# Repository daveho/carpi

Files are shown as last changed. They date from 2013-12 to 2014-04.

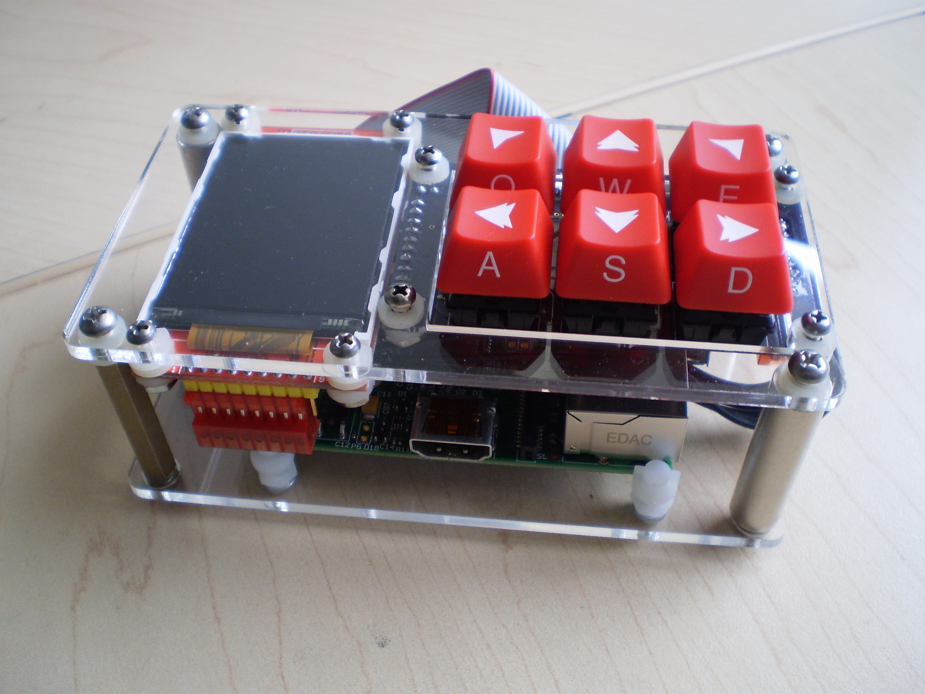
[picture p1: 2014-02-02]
enclosure/pic-big.jpg

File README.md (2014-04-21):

Hardware design and code for Raspberry Pi based car entertainment device.  Everything is up and running and works fairly well at this point.  I wrote a [blog post](http://daveho.github.io/2014/04/19/carpi-car-videos-with-the-raspberry-pi.html) that summarizes the project.

The [wiki](https://github.com/daveho/carpi/wiki) has complete information on building the device and installing the software.

Everything (software and hardware) is open source: see the file
LICENSES.txt for details.

The basic idea is being able to play videos and music
from the Raspberry Pi.  The user interface consists
of a 2.2" LCD and 6 keyswitches.  A sandwich-style
enclosure consisting of two pieces of laser-cut acrylic
and various bits of hardware has been designed and assembled.
The "enclosure" directory has complete CAD drawings.

Here is a photo of the assembled device (with the Raspberry Pi,
the LCD module, and the keyswitches):



Current status of the software is

* It's a console (ncurses) app.  This probably won't change,
  although the software makes a clean separation between
  controllers and views, and the former are completely
  independent of the latter, so a proper GUI interface
  could be supported.
* The LCD display is assumed to be 240x320, accessed as
  a Linux framebuffer device with fbcons.  (Specifically,
  an SPI-based LCD using the ILI9340 controller chip,
  supported by fbtft using the "adafruit22a" driver.
  Note that the LCD I'm using isn't specifically the
  Adafruit one, but appears to be completely compatible.)
  With a 8x16 font this gives us a 30x20 text display.
* Music playing works using mpg321 and ogg123 via the
  remote control interface (actually ogg123 playback doesn't
  work, need to investigate this).
* Pushbutton input is supported using the RPi's GPIO.
* Video playing is supported by running omxplayer as a
  subprocess, with video output going to the composite output
  (because composite video monitors for cars are super cheap).

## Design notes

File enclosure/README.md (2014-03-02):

The enclosure designs were created with LibreCAD.

Here's how it looks completely assembled (click for large version)!



Files:

* plate2.dxf - the main drawing showing all of the features of the top and bottom plates of the enclosure, including the Raspberry Pi, the LCD, the buttons PCB, standoffs, etc.
* top2.dxf, bottom2.dxf - drawings with just the cuts needed for the top and bottom plates
* combined2.dxf - combined drawing of top and bottom plates; this can be submitted to your favorite laser cutting service (I personally think [Pololu](http://www.pololu.com/) is awesome!)
* ibex\_rpi\_model\_b\_v1\_00.dxf - CAD drawing of the Raspberry Pi,
  taken from http://www.raspberry-projects.com/pi/pi-hardware/model-b-cad
* ibex\_rpi\_model\_b\_v1\_00\_correct\_orientation.dxf -
  same as above, but shown as a top view instead of a bottom view
* lcd.dxf - drawing of just the LCD module, showing screw hole locations
* buttons2.dxf - drawing of outline and screw holes for buttons PCB (v0.2, with Cherry MX keyswitches)

The **old** subdirectory has a previous version of the enclosure where the buttons were 12mm x 12mm pushbuttons: not recommended, since I messed up the header orientation on the v0.1 buttons PCB, and it will be very difficult to connect it to the Raspberry Pi.

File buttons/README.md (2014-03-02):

This directory has schematics, PCB layout, and firmware for the
board that has the pushbuttons on it.  An attiny2313 or attiny4313
microcontroller does the debouncing.  This board also has a header
that connects to the LCD.

**buttons2.sch** and **buttons2.brd** are the schematic and board layout,
in Eagle CAD.

Rendering (via [OSH Park](http://www.oshpark.com), which is where I had the boards fabricated):

<a href="https://raw.github.com/daveho/carpi/master/buttons/pcbBottom.png">bottom of PCB</a>

<a href="https://raw.github.com/daveho/carpi/master/buttons/pcbTop.png">top of PCB</a>

Note that the PCB uses Cherry MX keyboard switches.  **cherrymx.lbr** is a
(very slightly) modified version of the following Eagle library:
https://github.com/c0z3n/cherrymx-eagle

[I sent a pull request with my changes, which were purely improvements
to the schematic symbol.]

**buttons.c** is the firmware that runs on the attiny2313.
**Makefile** will compile it (using avr-gcc) and program it to the
device (using avrdude).

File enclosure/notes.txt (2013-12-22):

ibex_rpi_model_b_v1_00.dxf is from:
  http://www.raspberry-projects.com/pi/pi-hardware/model-b-cad

ibex_rpi_model_b_v1_00_correct_orientation.dxf
  This is a modified version of the above file with the contents
  mirrored to show a top view rather than a bottom view.
  (Not quite sure why the original was a bottom view.)

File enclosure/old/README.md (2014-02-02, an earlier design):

This is an old version of the enclosure design.  You don't want to use this.

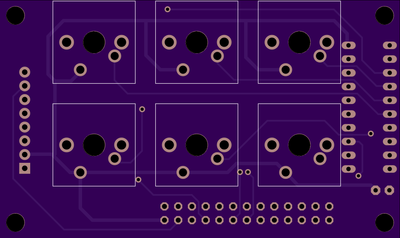
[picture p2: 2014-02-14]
buttons/pcbTop-sm.png

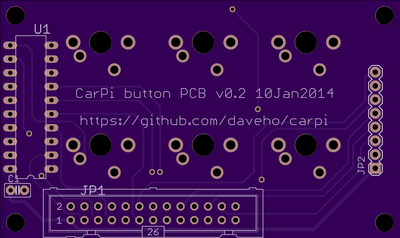
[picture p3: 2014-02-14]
buttons/pcbBottom-sm.png

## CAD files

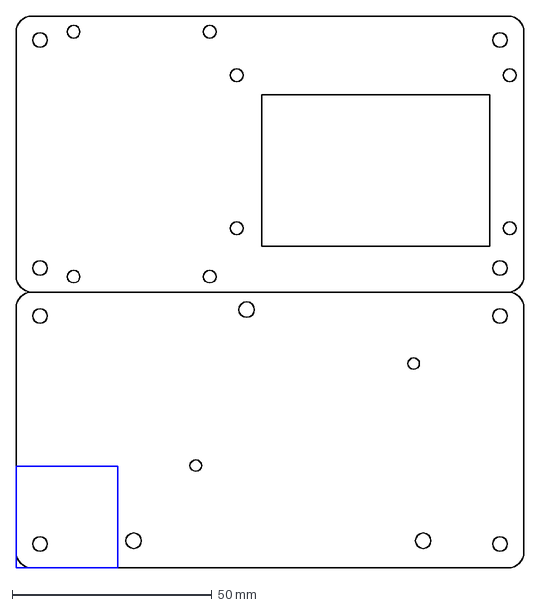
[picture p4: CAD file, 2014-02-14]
enclosure/combined2.dxf
127.0 x 138.0 mm

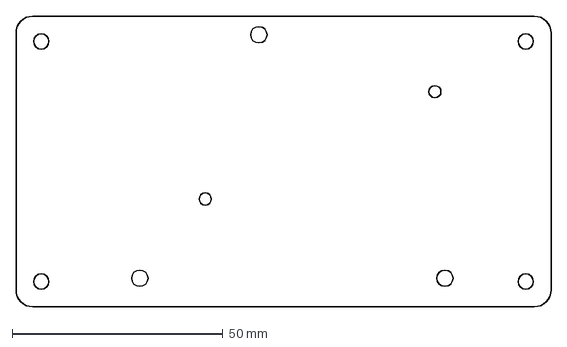
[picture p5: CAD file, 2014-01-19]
enclosure/bottom2.dxf
127.0 x 69.0 mm

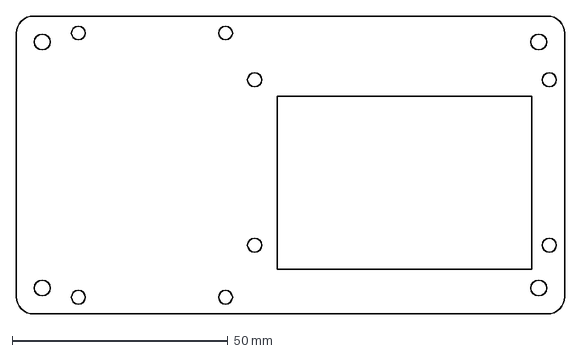
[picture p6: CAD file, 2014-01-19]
enclosure/top2.dxf
127.0 x 69.0 mm

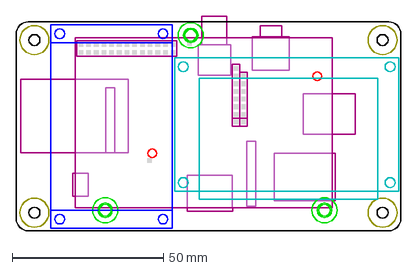
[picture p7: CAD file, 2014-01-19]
enclosure/plate2.dxf
127.0 x 70.9 mm

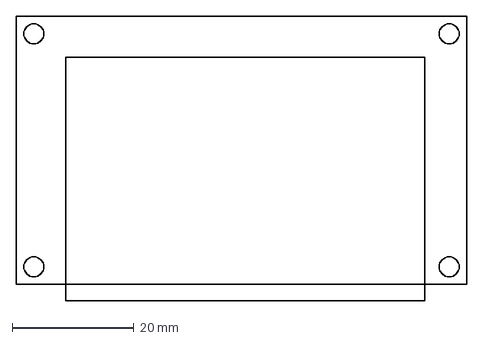
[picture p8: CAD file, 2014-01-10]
enclosure/buttons2.dxf
74.0 x 46.7 mm

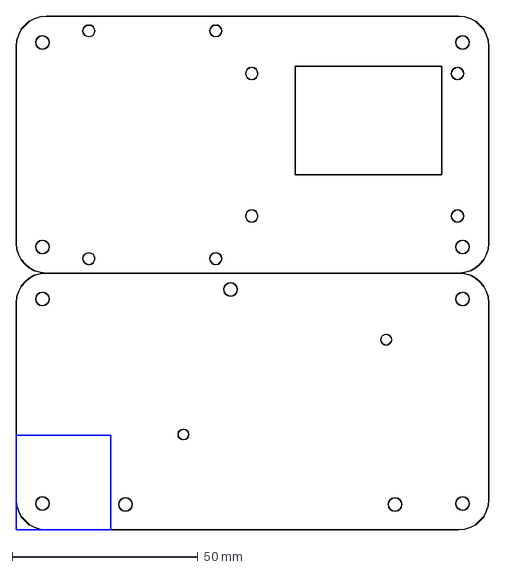
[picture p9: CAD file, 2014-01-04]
enclosure/combined.dxf
127.0 x 138.0 mm

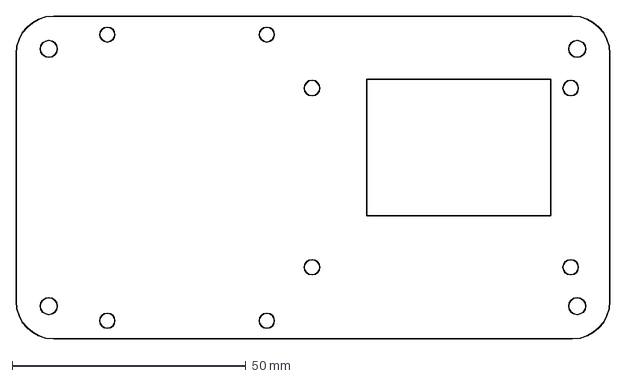
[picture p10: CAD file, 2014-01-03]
enclosure/top.dxf
127.0 x 69.0 mm

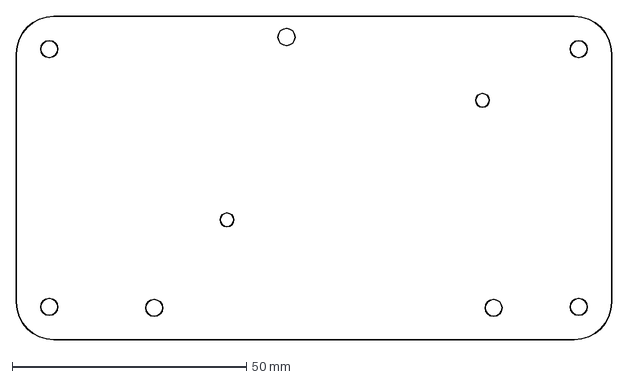
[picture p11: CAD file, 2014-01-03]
enclosure/bottom.dxf
127.0 x 69.0 mm

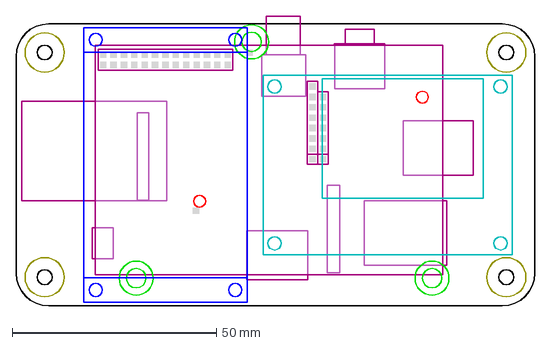
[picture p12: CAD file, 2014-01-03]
enclosure/plate.dxf
127.0 x 70.9 mm

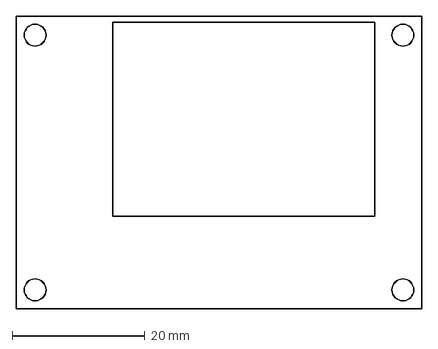
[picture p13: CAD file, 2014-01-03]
enclosure/buttons.dxf
61.0 x 44.0 mm

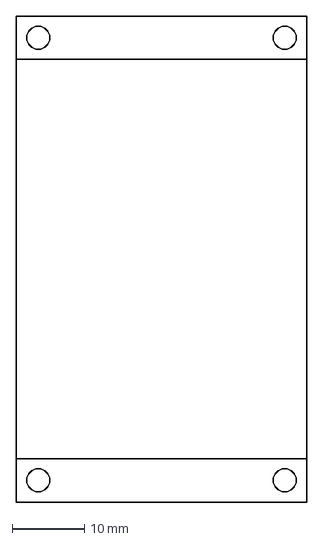
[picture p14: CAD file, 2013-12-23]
enclosure/lcd.dxf
40.1 x 67.2 mm

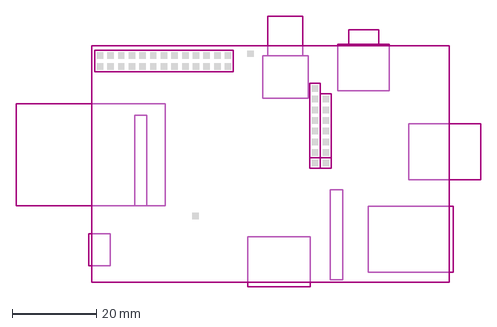
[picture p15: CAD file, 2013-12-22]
enclosure/ibex_rpi_model_b_v1_00_correct_orientation.dxf
110.5 x 64.5 mm

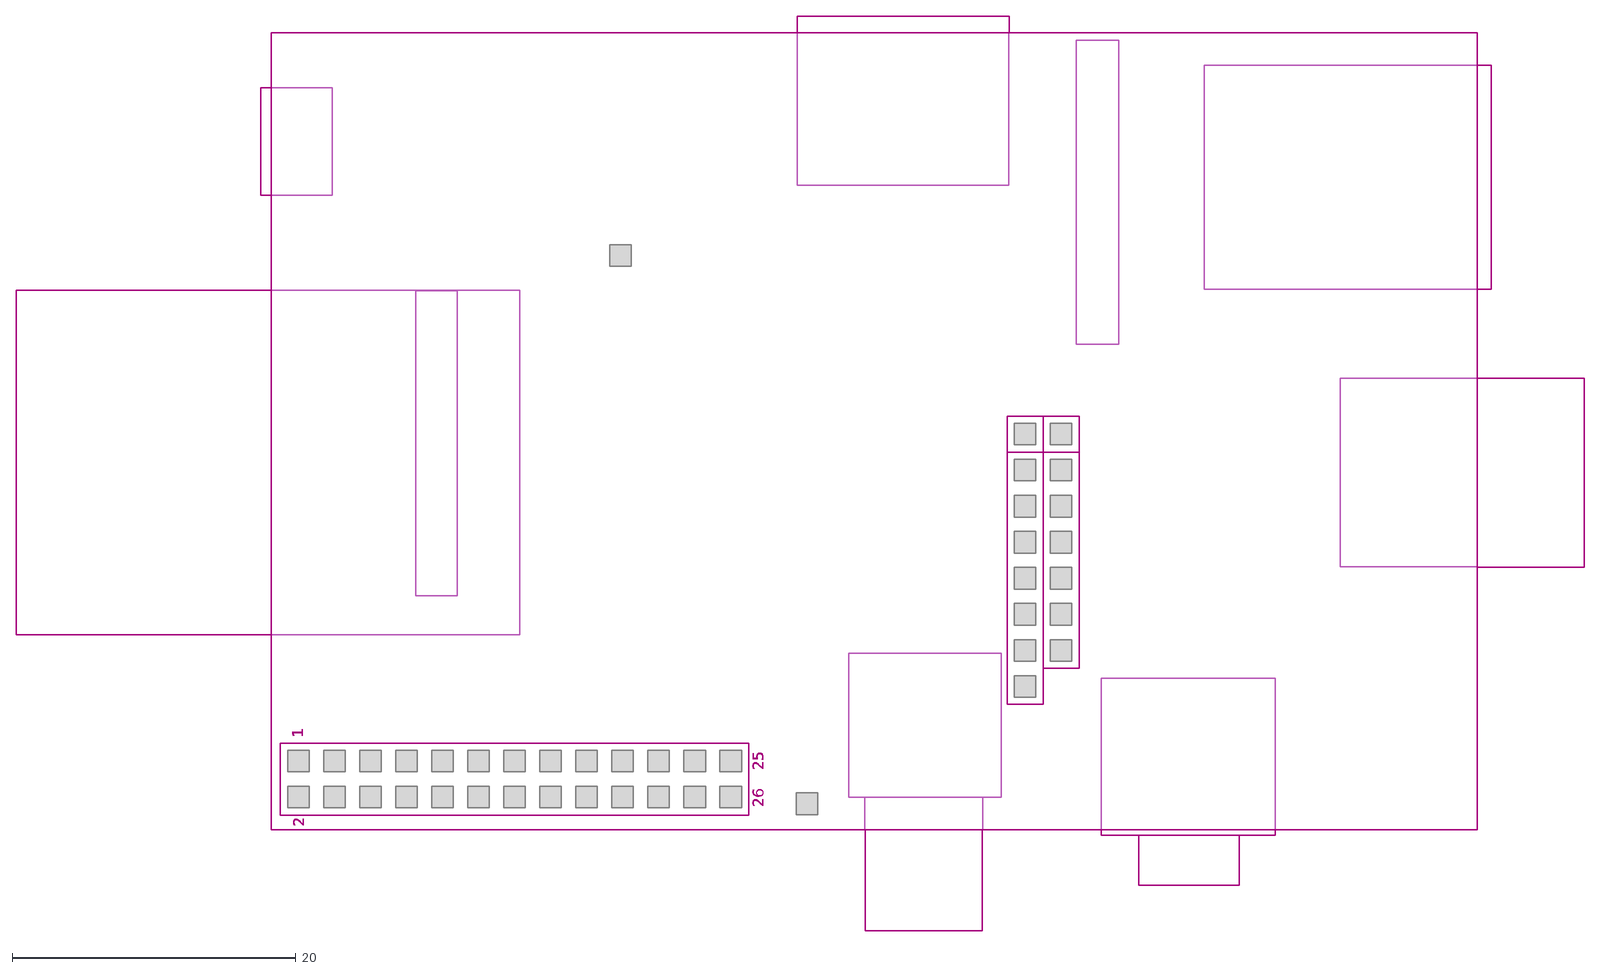
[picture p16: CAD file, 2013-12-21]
enclosure/ibex_rpi_model_b_v1_00.dxf
26
25
2
1

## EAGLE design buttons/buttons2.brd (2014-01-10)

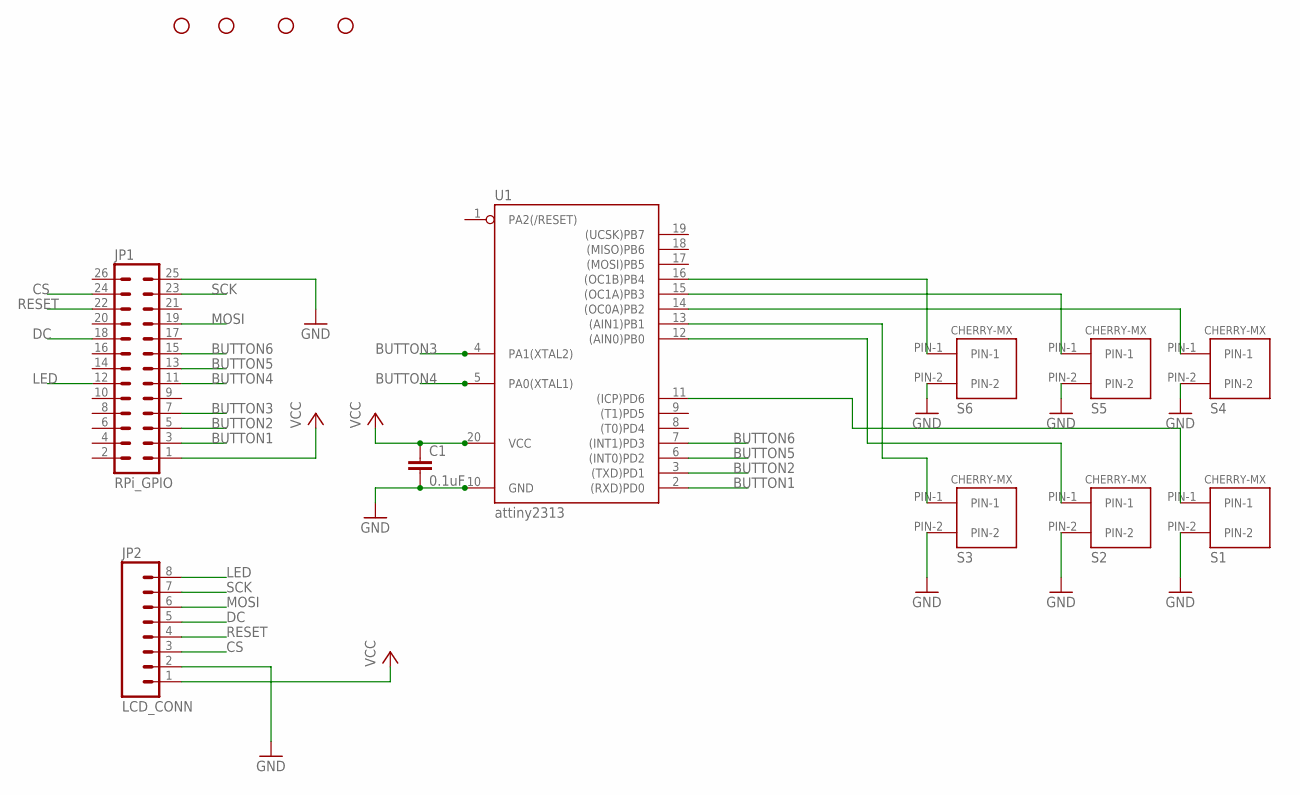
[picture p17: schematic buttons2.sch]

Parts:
C1: 0.1uF; C2.5-2
JP1: RPi_GPIO; ML26
JP2: LCD_CONN; 1X08
S1, S2, S3, S4, S5, S6: CHERRY-MX-I
STANDOFF1, STANDOFF2, STANDOFF3, STANDOFF4: STAND-OFF
U1: attiny2313; DIL20

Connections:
BUTTON1: JP1.3, U1.2 ((RXD)PD0)
BUTTON2: JP1.5, U1.3 ((TXD)PD1)
BUTTON3: JP1.7, U1.4 (PA1(XTAL2))
BUTTON4: JP1.11, U1.5 (PA0(XTAL1))
BUTTON5: JP1.13, U1.6 ((INT0)PD2)
BUTTON6: JP1.15, U1.7 ((INT1)PD3)
CS: JP1.24, JP2.3
DC: JP1.18, JP2.5
GND: C1.2, JP1.25, JP2.2, S1.PIN-2, S2.PIN-2, S3.PIN-2, S4.PIN-2, S5.PIN-2, S6.PIN-2, U1.10 (GND)
LED: JP1.12, JP2.8
MOSI: JP1.19, JP2.6
unnamed: S6.PIN-1, U1.16 ((OC1B)PB4)
unnamed: S5.PIN-1, U1.15 ((OC1A)PB3)
unnamed: S4.PIN-1, U1.14 ((OC0A)PB2)
unnamed: S3.PIN-1, U1.13 ((AIN1)PB1)
unnamed: S2.PIN-1, U1.12 ((AIN0)PB0)
unnamed: S1.PIN-1, U1.11 ((ICP)PD6)
RESET: JP1.22, JP2.4
SCK: JP1.23, JP2.7
VCC: C1.1, JP1.1, JP2.1, U1.20 (VCC)

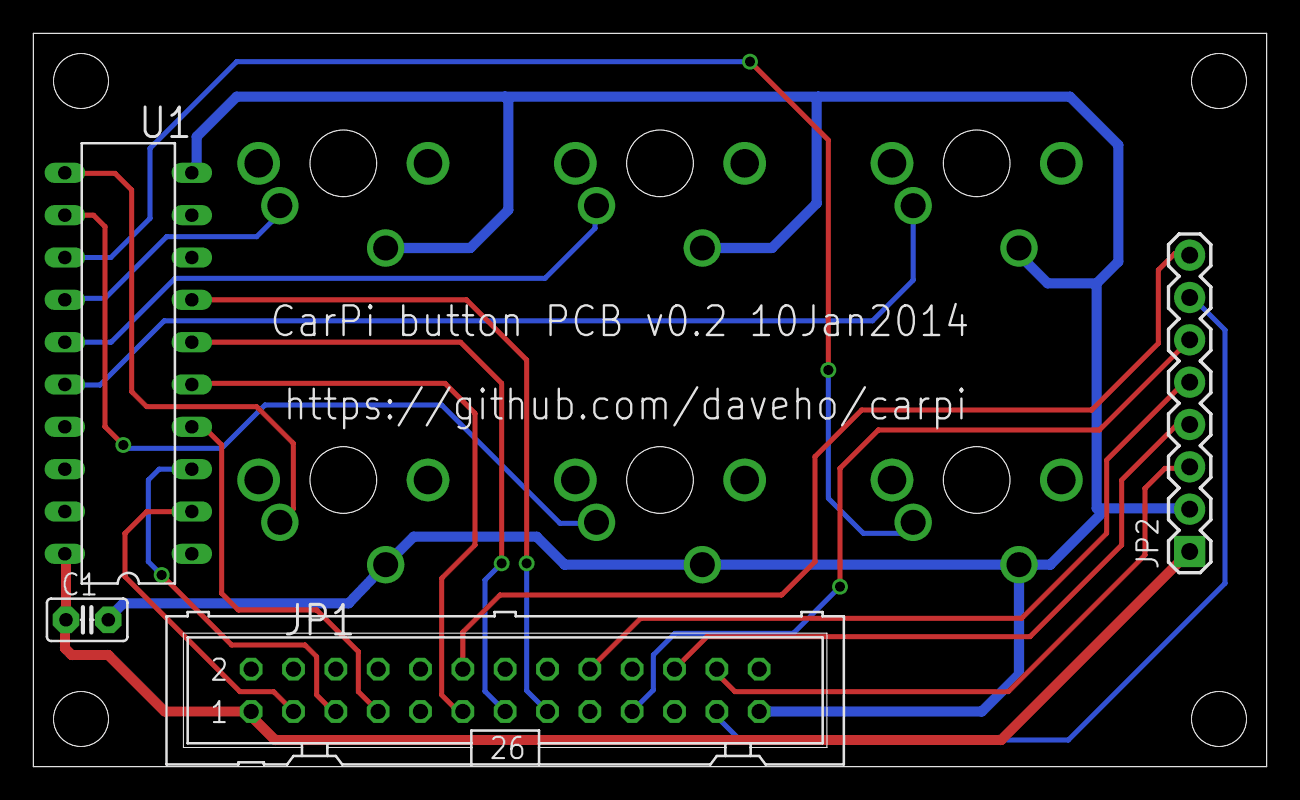
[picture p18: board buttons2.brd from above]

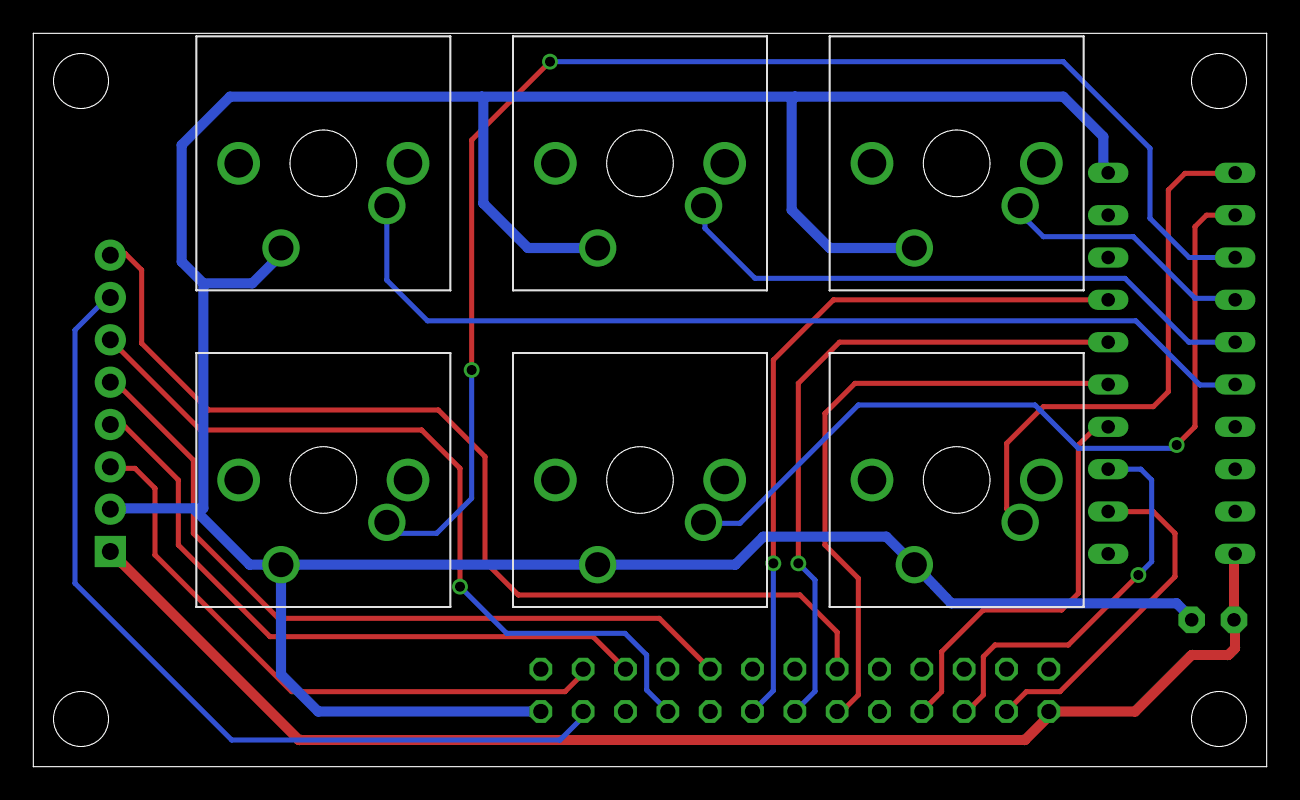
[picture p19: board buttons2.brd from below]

Board: 2 copper layers, 74.0 x 44.0 mm, 14 parts (6 on the bottom side), 20 nets.

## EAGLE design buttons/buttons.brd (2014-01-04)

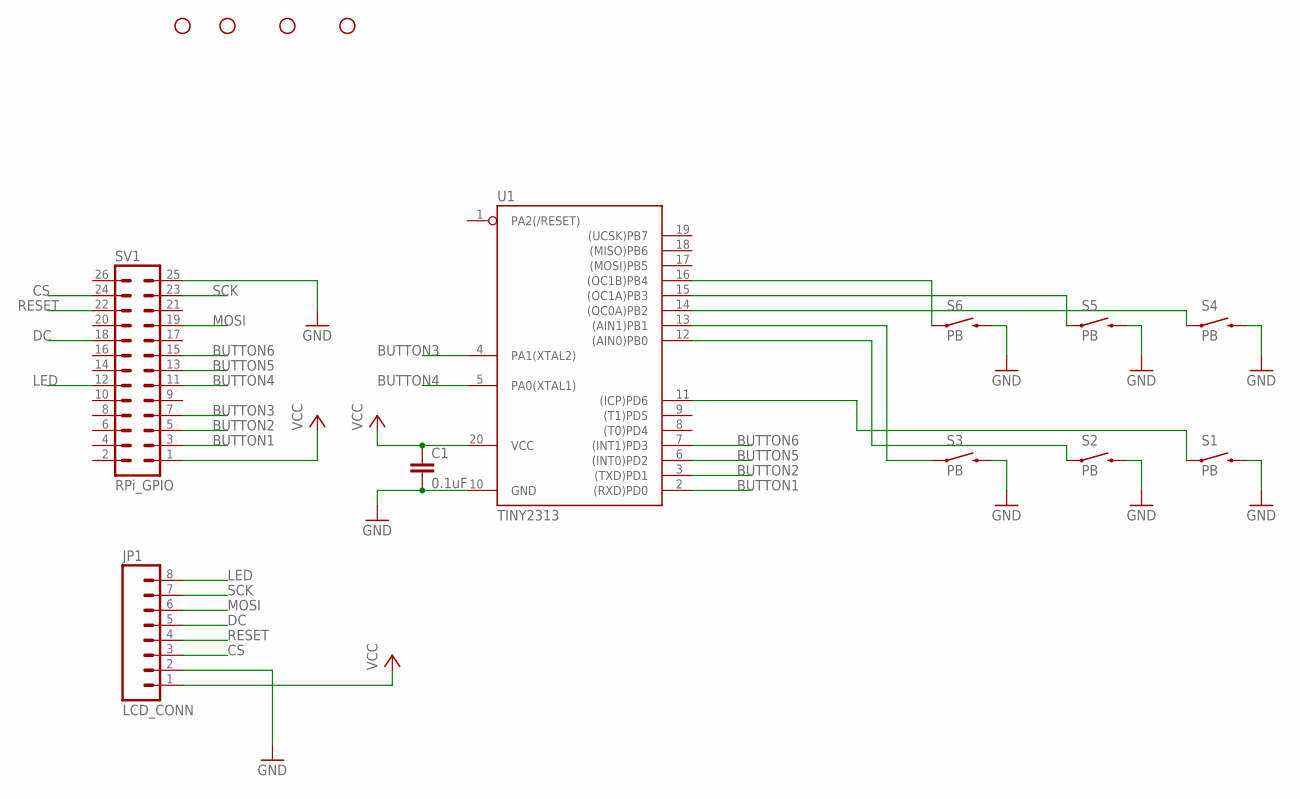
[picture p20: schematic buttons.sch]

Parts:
C1: 0.1uF; C2.5-2
JP1: LCD_CONN; 1X08
S1, S2, S3, S4, S5, S6: PB; TACTILE-PTH-12MM
STANDOFF1, STANDOFF2, STANDOFF3, STANDOFF4: STAND-OFF
SV1: RPi_GPIO; ML26
U1: TINY2313; DIL20

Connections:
BUTTON1: SV1.3, U1.2 ((RXD)PD0)
BUTTON2: SV1.5, U1.3 ((TXD)PD1)
BUTTON3: SV1.7, U1.4 (PA1(XTAL2))
BUTTON4: SV1.11, U1.5 (PA0(XTAL1))
BUTTON5: SV1.13, U1.6 ((INT0)PD2)
BUTTON6: SV1.15, U1.7 ((INT1)PD3)
CS: JP1.3, SV1.24
DC: JP1.5, SV1.18
GND: C1.2, JP1.2, S1.3 (2), S2.3 (2), S3.3 (2), S4.3 (2), S5.3 (2), S6.3 (2), SV1.25, U1.10 (GND)
LED: JP1.8, SV1.12
MOSI: JP1.6, SV1.19
unnamed: S6.1, U1.16 ((OC1B)PB4)
unnamed: S5.1, U1.15 ((OC1A)PB3)
unnamed: S4.1, U1.14 ((OC0A)PB2)
unnamed: S3.1, U1.13 ((AIN1)PB1)
unnamed: S2.1, U1.12 ((AIN0)PB0)
unnamed: S1.1, U1.11 ((ICP)PD6)
RESET: JP1.4, SV1.22
SCK: JP1.7, SV1.23
VCC: C1.1, JP1.1, SV1.1, U1.20 (VCC)

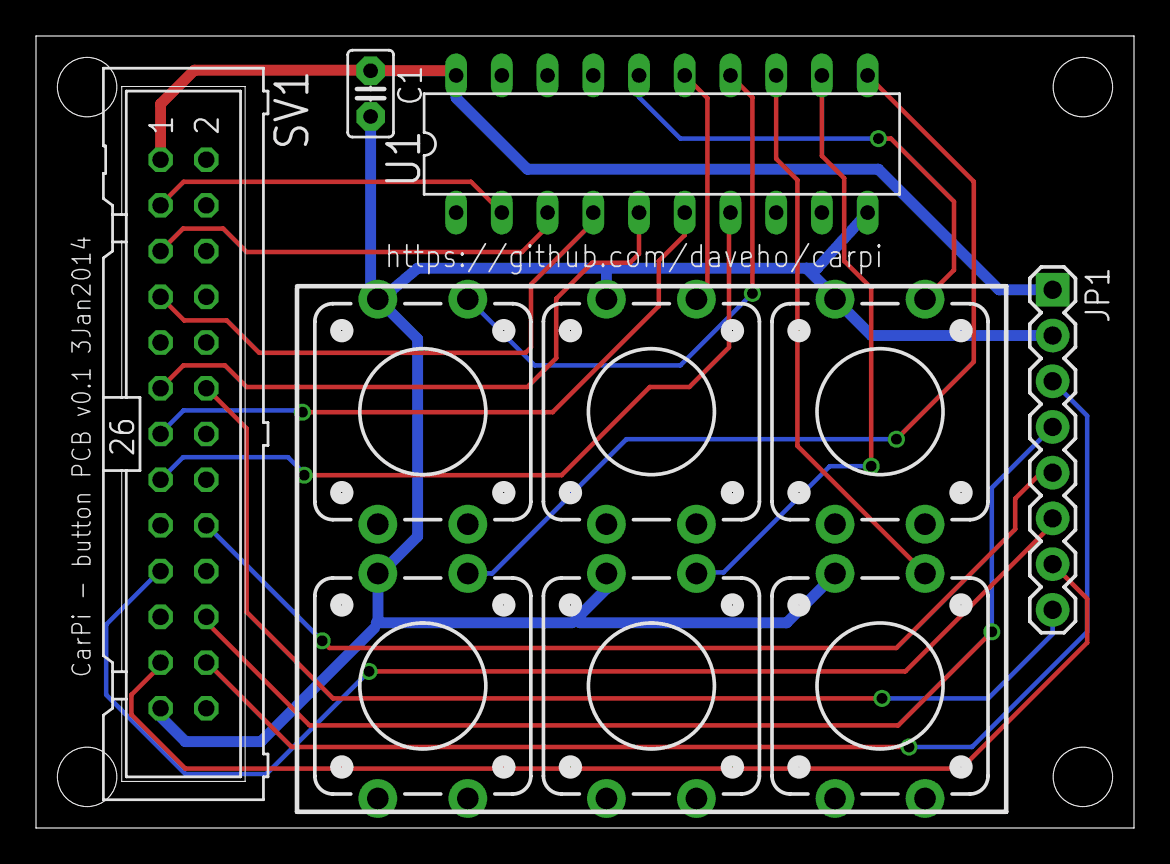
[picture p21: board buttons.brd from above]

Board: 2 copper layers, 61.0 x 44.0 mm, 14 parts (0 on the bottom side), 20 nets.

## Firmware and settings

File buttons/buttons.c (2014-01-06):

// CarPi - Raspberry Pi car entertainment system
// Copyright (c) 2013,2014 David H. Hovemeyer <david.hovemeyer@gmail.com>

// This file is part of CarPi.
// 
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
// Use attiny2313 to debounce 6 pushbuttons
// The buttons should connect to ground when pressed

#define F_CPU 1000000 // use internal oscillator, set to 1 MHz
#include <stdint.h>
#include <avr/io.h>
#include <avr/interrupt.h>
#ifdef USE_LOW_POWER_MODE
#  include <avr/sleep.h>
#endif
#include <util/delay.h>

// Input level must be stable for at least this many
// time units, where a time unit is 1/4096 sec.
#define DEBOUNCE_TIME 16

// Inputs (0=pressed)
// Button 1 - PD6
// Button 2 - PB0
// Button 3 - PB1
// Button 4 - PB2
// Button 5 - PB3
// Button 6 - PB4

// Outputs (debounced button values, 0=pressed)
// Button 1 - PD0
// Button 2 - PD1
// Button 3 - PA1
// Button 4 - PA0
// Button 5 - PD2
// Button 6 - PD3

// Bit masks for output pins on ports A and D
#define PORTA_OUTPUT_MASK (_BV(PA0)|_BV(PA1))
#define PORTD_OUTPUT_MASK (_BV(PD0)|_BV(PD1)|_BV(PD2)|_BV(PD3))

uint8_t g_cur = 0x3F;      // current input values
uint8_t g_last = 0x3F;     // last input values
uint8_t g_count[6];        // count of how many polls buttons have had their current values
uint8_t g_out = 0x3F;      // current output values

#ifndef NDEBUG
uint16_t g_debug_count = 0;
#endif

void read_inputs(void);
void update_counts(void);
void write_outputs(void);

// Timer interrupt, called once per 1ms
ISR(TIMER0_OVF_vect)
{
	read_inputs();
	update_counts();
	write_outputs();
	g_last = g_cur;

#ifndef NDEBUG
	// Blink LED on PD4 for debugging
	g_debug_count++;
	if ((g_debug_count & 0x1FF) == 0) {
		PORTD ^= _BV(PD4);
	}
#endif
}

int main(void)
{
	// Ensure all pins on port B are input
	DDRB = 0;

	// Enable PA0-1, PD0-3 as outputs
	DDRA = PORTA_OUTPUT_MASK;
	DDRD = PORTD_OUTPUT_MASK;
#ifndef NDEBUG
	DDRD |= _BV(PD4);
#endif

	// Enable internal pull-up resistors on all pins that aren't
	// being used as outputs
	PORTA = ~PORTA_OUTPUT_MASK;
	PORTB = 0xFF;
	PORTD = ~PORTD_OUTPUT_MASK;

	// Set up timer interrupt to fire 4096 times per second
	TCCR0B |= (1<<CS00);   // no prescaling
	TIMSK |= (1 << TOIE0); // interrupt on overflow of counter 0

	// Enable interrupts
	sei();

	// At this point, the interrupt handler should
	// do all of the work.
	for (;;) {
#ifdef USE_LOW_POWER_MODE
		// The main loop attempts to spend as
		// much time as possible in low-power mode.
		cli();
		sleep_enable();
		sei();
		sleep_cpu();
#endif
	}
}

void read_inputs(void)
{
	// Process buttons in reverse order: button 1 is the
	// least significant bit
	uint8_t inb = PINB;
	uint8_t ind = PIND;
	g_cur = 0;

	// Read input for button 6
	g_cur |= ((inb & _BV(PB4)) != 0); // button 6
	g_cur <<= 1;

	// Read input for buttons 5-1
	g_cur |= ((inb & _BV(PB3)) != 0); // button 5
	g_cur <<= 1;
	g_cur |= ((inb & _BV(PB2)) != 0); // button 4
	g_cur <<= 1;
	g_cur |= ((inb & _BV(PB1)) != 0); // button 3
	g_cur <<= 1;
	g_cur |= ((inb & _BV(PB0)) != 0); // button 2
	g_cur <<= 1;
	g_cur |= ((ind & _BV(PD6)) != 0); // button 1
}

void update_counts(void)
{
	// Update counts, allow outputs to change if count is
	// sufficiently high
	uint8_t nextout = g_out;
	for (uint8_t i = 0, mask = 1; i < 6; i++, mask <<= 1) {
		if ((g_cur & mask) == (g_last & mask)) {
			// Button input value is same as last poll: increment count
			if (g_count[i] < 255) { g_count[i]++; }
		} else {
			// Button input value is different from last poll:
			// reset count to 0
			g_count[i] = 0;
		}

		// Allow output to change if count is sufficiently high
		if (g_count[i] > DEBOUNCE_TIME && (g_cur & mask) != (g_out & mask)) {
			nextout ^= mask;
		}
	}

	g_out = nextout;
}

void write_outputs(void)
{
	// Get current port A/D values, but leaving 0s for the bits
	// corresponding to the button outputs we want to generate
	uint8_t outa = PORTA & ~PORTA_OUTPUT_MASK;
	uint8_t outd = PORTD & ~PORTD_OUTPUT_MASK;

	// Set button output bits in port A/D as appropriate.
	// Note that the button inputs are 0=pressed, and we generate
	// the debounced outputs as 0=pressed.
	// There is a good reason for this: if a 0 (ground) is
	// asserted on the RPi's SCL pin, it boots in safe mode,
	// which we don't want to happen by default.
	uint8_t genout = g_out;
	if ((genout & 1) != 0) { outd |= _BV(PD0); }
	genout >>= 1;
	if ((genout & 1) != 0) { outd |= _BV(PD1); }
	genout >>= 1;
	if ((genout & 1) != 0) { outa |= _BV(PA1); }
	genout >>= 1;
	if ((genout & 1) != 0) { outa |= _BV(PA0); }
	genout >>= 1;
	if ((genout & 1) != 0) { outd |= _BV(PD2); }
	genout >>= 1;
	if ((genout & 1) != 0) { outd |= _BV(PD3); }

	// Update outputs!
	PORTA = outa;
	PORTD = outd;
}

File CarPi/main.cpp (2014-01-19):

// CarPi - Raspberry Pi car entertainment system
// Copyright (c) 2013,2014 David H. Hovemeyer <david.hovemeyer@gmail.com>

// This file is part of CarPi.
// 
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
//#ifdef RASPBERRY_PI
//#  define GPIO_TEST
//#endif

#ifdef GPIO_TEST
#  include <sys/select.h>
#  include <cstdio>
#  include <cstdlib>
#  include "gpio_pin.h"
#else
#  include "cons_car_pi_app.h"
#endif

#ifdef GPIO_TEST
void gpioTest()
{
	GpioPin pinList[6];

	/*
	 * Button 1: GPIO2 (P1-3)
	 * Button 2: GPIO3 (P1-5)
	 * Button 3: GPIO4 (P1-7)
	 * Button 4: GPIO17 (P1-11)
	 * Button 5: GPIO27 (P1-13)
	 * Button 6: GPIO22 (P1-15)
	 */
	pinList[0].initForReading(2);
	pinList[1].initForReading(3);
	pinList[2].initForReading(4);
	pinList[3].initForReading(17);
	pinList[4].initForReading(27);
	pinList[5].initForReading(22);

	// Check that initializing the pins succeeded
	for (int i = 0; i < 6; i++) {
		if (!pinList[i].isActive()) {
			printf("Pin %d not active?\n", pinList[i].getPinNumber());
			exit(1);
		}
	}
	printf("Pins initialized correctly?\n");

	// Set the interrupt mode on each pin so that an interrupt is triggered
	// on both rising and falling edges
	for (int i = 0; i < 6; i++) {
		pinList[i].setInterruptMode(GpioPin::BOTH);
	}

	// Verify that interrupt mode was set correctly
	for (int i = 0; i < 6; i++) {
		if (pinList[i].getInterruptMode() != GpioPin::BOTH) {
			printf("Couldn't set interrupt mode on pin %d\n", pinList[i].getPinNumber());
		}
	}
	printf("Set interrupt modes correctly?\n");

	// Print changing pin values, using select to block waiting
	// for an interrupt.  According to the Linux GPIO documentation,
	// the pin value fds should be in the exception set
	// (not the read or write sets).
	fd_set pinSet;
	int highestFd = GpioPin::makeFdSet(&pinSet, pinList, 6);

	for (;;) {
		for (int i = 0; i < 6; i++) {
			printf("%d", pinList[i].getValue());
		}
		printf("\n");

		fd_set waitSet(pinSet);
		int rc = select(highestFd+1, 0, 0, &waitSet, 0);
		if (rc < 0) {
			printf("Select failed?\n");
			break;
		}
	}
}
#endif

int main(void)
{
#ifdef GPIO_TEST
	gpioTest();
#else
	ConsCarPiApp::initialize();
	CarPiApp::instance()->mainLoop();
#endif
	return 0;
}

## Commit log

2013-12-21 started log, enclosure design
    [plate.dxf, top.dxf]
2013-12-21 made it 5"x3" to allow room for board mounts
    [plate.dxf]
2013-12-21 initial checkin
    [plate-with-rpi.dxf]
2013-12-21 rpi model B CAD drawing
    [ibex_rpi_model_b_v1_00.dxf]
2013-12-22 new plate size, Rpi outline w/ ref at 0,0
    [rpi_outline.dxf]
2013-12-22 corrected orientation of Rpi outline
    [ibex_rpi_model_b_v1_00_correct_orientation.dxf]
2013-12-22 locations for board mounts
    The outer radius is the "platform" that goes under the
    board. The inner radius is the "cap" that clamps down on
    the PCB (and which must be clear of features on the top
    of the PCB).
    From the drawing it looks like there are some reasonable
    locations, but I need to check it visually against the
    actual RPi to make sure that there is nothing protruding
    on the top or bottom that would get in the way.
    I feel fairly confident that in conjunction with the
    standoffs below the mounting holes, I can get a pretty
    secure mounting for the RP.
    The 5"x2.75" form factor seems to work quite well - the
    screw holes for the board mounts won't be unreasonably
    close to the edge of the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
    [plate.dxf]
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2013-12-23 moved board mounts to avoid hitting stuff on pcb
    From visual inspection of the RPi, there are various
    things on the underside of the PCB that the board mounts
    would have hit in their original positions. Moved them
    to places where the top and bottom are clear. One
    issue is that the corner with the GPIO header has no
    board mount - there doesn't seem to be any good place
    for one. Will double-check when the board mounts
    arrive and I can try them out on the actual RPi to
    see how they fit.
    [plate.dxf]
2013-12-23 move standoffs and RPi for better clearance
    Added a layer to the drawing to show the approximate size
    of the standoffs. Was concerned that the bottom right
    standoff would block access to the ethernet port, so moved
    all of the standoffs 1mm horizontally and vertically
    towards the corners, and moved the RPi further towards
    the top. This should allow good clearance for the
    ethernet.
    [plate.dxf]
2013-12-23 starting drawing of LCD
    [lcd.dxf]
2013-12-23 just doing a single drawing for now...
    [plate-with-rpi.dxf, top.dxf]
2013-12-23 basic drawing of LCD
    [lcd.dxf]
2013-12-23 change LCD orientation to vertical
    This is really the only way the buttons will fit. This
    seems to be the preferred orientation for the LCD anyway.
    [lcd.dxf, plate.dxf]
2013-12-23 started outline of buttons protoboard
    [buttons.dxf]
2013-12-23 5x7mm protoboard for buttons won't fit :-(
    [buttons.dxf, plate.dxf]
2013-12-23 updates for using 4x6cm board for buttons
    [buttons.dxf, plate.dxf]
2013-12-24 restart code, starting with audio player
    Created PlaySound class, for playing an audio file using
    mpg321 or ogg123 using their remote control interface.
    Using CodeLite as the C++ IDE.
    [plate.dxf]
2013-12-24 started Thread, Event, and EventQueue classes
    Modified PlaySound to use a Thread subclass for the
    status monitor thread.
2013-12-25 starting on UI
    Trying to put in a relatively GUI-agnostic framework
    without making things unnecessarily complicated. Initial
    implementation is ncurses, but I want to leave open
    the possibility of an actual GUI implementation in
    the future.
    One thing that is missing is controllers: views should
    only handle events related to painting and updates of
    model objects.
    Things kind of work at this point: a menu is displayed,
    but changing the selection doesn't work.
2013-12-26 started main menu
    There will be one menu class and one menu controller class
    per menu. Seems to be workable. The controller will
    "own" the menu, and thus be responsible for cleaning it
    up when the controller and view are no longer needed.
    [main.cpp]
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2013-12-27 adjusted for larger diameter standoffs
    [plate.dxf]
2013-12-28 fix bugs in id3 parsing
    [main.cpp]
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2013-12-31 attempted fix for ogg123 failing to send @P msgs
    ogg123 doesn't send a @P message when the current file
    has finished playing, meaning that we don't know to
    start the next file playing. Attempt to work around
    by generating a status callback at the appropriate time.
    Doesn't actually work - investigating.
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2014-01-02 blink LED on PD4 for debugging
    Also, stick with default 1 MHz internal oscillator - I bricked
    one of my attiny2313 trying to configure the fuses for 128 KHz
    internal oscillator. Button press detection doesn't seem to
    work, but blinking LED does work.
    [buttons.c]
2014-01-02 pass-through without debouncing works
    Clearly there is something wrong with the debouncing
    code, but the circuit works fine. I may send the board
    off to be manufactured!
    [buttons.c]
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2014-01-02 debouncing code works perfectly!
    I was shifting the mask bit twice per loop iteration.
    Changed Makefile so that debugging (the heartbeat LED blink
    on PD4) is disabled by default.
2014-01-03 placed buttons in wrong order on PCB
    I laid out the buttons in exactly the opposite order
    on the PCB, so I needed to change the firmware to
    compensate. Not a big deal.
    [buttons.c]
2014-01-03 updated for new PCB design
    [buttons.dxf]
2014-01-03 adjust standoff positions
    Each standoff is exactly 2.84mm V/H from the board edges.
    [buttons.dxf]
2014-01-03 larger board (keep standoffs from cutout)
    [buttons.dxf]
2014-01-03 added exact outline of button cutout
    [buttons.dxf]
2014-01-03 added updated outline for button board
    [plate.dxf]
2014-01-03 top and bottom plates!
    [bottom.dxf, top.dxf]
2014-01-03 combined top/bottom plate drawing
    [combined.dxf]
2014-01-04 added 1"x1" reference square
    [combined.dxf]
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2014-01-04 readme/license information
    [buttons.brd, buttons.sch, rpi_outline.dxf]
2014-01-04 bugfix in StringUtil::padWithSpaces
    wasn't properly handling the case where the string
    was greater than the desired field width
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2014-01-05 updated for interrupt-driver low power operation
    Polling is done 4096 times per sec based on a timer
    interrupt.
    The main loop attempts to put the CPU in low-power
    mode between interrupts.
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2014-01-06 output button signals as 0=pressed
    This avoids accidentally causing the RPi to boot in
    safe mode, which happens if SCL (GPIO 3) is held low on
    boot.
    [buttons.c]
2014-01-06 button circuit now seems to interface properly
    Next step is to read button inputs from software.
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2014-01-08 experiment to use Cherry MX keyboard switches
    [buttons2.brd, buttons2.dxf, buttons2.sch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]
2014-01-08 I think I have a workable Cherry MX design
    [buttons2.brd, buttons2.dxf, buttons2.sch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]
2014-01-08 working on signal routing
    [buttons2.brd]
2014-01-09 rip up traces to buttons, move attiny2313
    Buttons need to be mirrored because they will be
    on the bottom of the board.
    The attiny2313 was too close to the top left standoff.
    [buttons2.brd]
2014-01-09 mirrored buttons
    [buttons2.brd]
2014-01-09 routed all signals
    [buttons2.brd]
2014-01-09 more work on button PCB, but not done
    Problem is that the buttons need to be rotated
    180 degrees! Because the board will be flipped,
    the top of the PCB will be towards the bottom
    of the top plate of the enclosure. Duh.
    [buttons2.brd, buttons2.sch]
2014-01-09 more or less complete PCB for Cherry MX switches
    [buttons2.brd]
2014-01-09 moved buttons: keycaps are 18mm x 18mm
    I think everything will still fit, but unfortunately
    everything must be routed again...
    [buttons2.brd]
2014-01-09 finished routing updated buttons2 PCB
    This has (I think) adequate clearance for an 18mm x 18mm
    keycap: the centers of the switches are 18.5mm apart, hopefully
    this is enough room.
    [buttons2.brd, buttons2.dxf, buttons2.sch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]
2014-01-09 some minor routing tweaks
    [buttons2.brd]
2014-01-09 move power trace away from standoff
    [buttons2.brd]
2014-01-09 making everything fit for Cherry MX keyswitches
    [buttons2.brd, buttons2.dxf, plate2.dxf]
2014-01-10 allow 19mm H/V between switch centers
    The keycaps are 18mm x 18mm, so hopefull this is enough
    room.
    [buttons2.brd]
2014-01-10 various layout tweaks, improved clearances, etc.
    [buttons2.brd]
2014-01-10 more minor routing improvements
    [buttons2.brd]
2014-01-10 more routing tweaks
    [buttons2.brd]
2014-01-10 updated buttons2/plate drawing for 19mm keycap
    Made the PCB 74mm rather than 73mm to allow more space
    between button cutout and button PCB screw hole.
    [buttons2.brd, buttons2.dxf, plate2.dxf]
2014-01-10 eliminated an unnecessary via
    [buttons2.brd]
2014-01-10 a few more routing improvements
    [buttons2.brd]
2014-01-10 move URL away from via
    Vias are plated, I guess, so would interrupt the
    silkscreen layer.
    [buttons2.brd]
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2014-01-12 set m_pinNumber even if pin init fails
    [gpio_pin.cpp, main.cpp]
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2014-01-12 made GpioPin::getValue const
    Also, verified that all pins are read correctly
    (they are)!
    [gpio_pin.cpp]
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2014-01-18 make corners less round, boardmount screw holes
    [plate2.dxf]
2014-01-18 note sure what changed :-)
    [plate2.dxf]
2014-01-18 bottom plate (new design with Cherry MX switches)
    The bottom plate just has holes for corner (plate)
    standoffs, board mounts, and RPi mounting hole standoffs.
    [bottom2.dxf]
2014-01-18 top plate (new design for Cherry MX switches)
    This has the corner standoff screw holes, LCD screw
    holes, button PCB screw holes, and the rectangular
    cutout for the keyswitches/keycaps.
    [top2.dxf]
2014-01-18 combined top/bottom plates (new design)
    [combined2.dxf]
2014-01-18 made side-by-side rather than on top of each other
    My thought is that this is easier to replicate multiple
    copies of.
    [combined2.dxf]
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2014-01-26 allow exiting the video player using left btn
    If the video is playing, the left button is
    ignored. The idea is to prevent accidental
    stoppages that might upset the viewers :-)
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2014-01-28 updated Enclosure design
    [bottom.dxf, buttons.dxf, combined.dxf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]
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2014-02-04 build ButtonDaemon by default
    Also, fixed a bug (initial button state was being set
    to pressed rather than released). And, added a debug
    printf so we can see when button events are generated.
    ButtonDaemon sort of works: however, key events only
    seem to appear every 4 presses. Seems to be some kind
    of buffering issue.
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2014-02-08 minor tweak - make key cutout smaller
    There is no possibility of the keycaps hitting the
    edges, so making the cutout smaller makes the clearance
    vis a vis the screw holes.
    [combined2.dxf]
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2014-03-02 bugfix with seek handling
    I'd forgotten to set EventHandler::HANDLED for up and
    down button presses, and to set m_rightPressed back to
    false.
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2017-07-05 always pass -o both
    This outputs audio to both HDMI and analog out: I thought the
    -o option was for *video* output, but apparently that is sent
    to the correct device automatically.

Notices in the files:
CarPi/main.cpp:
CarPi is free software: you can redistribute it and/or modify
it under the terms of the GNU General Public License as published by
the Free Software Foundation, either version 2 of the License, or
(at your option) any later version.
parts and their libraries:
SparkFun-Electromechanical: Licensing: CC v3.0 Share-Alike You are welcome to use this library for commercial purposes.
